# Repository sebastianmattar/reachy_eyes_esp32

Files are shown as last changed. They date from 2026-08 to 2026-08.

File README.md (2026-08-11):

# Eyes for the Reachy Mini

## Disclaimer

- This is a hobby project done with minimal professional knowledge of hardware development
- No guarantees of any kind are given
- I only tested this with my Reachy Mini Lite and MacOS
- Doing the modification can damage your robot
- Take extra care to not break the flat cables

## Motivation and journey

I wanted my Reachy Mini to have LED eyes to express different emotions.
Doing some research (googling) I figured I could combine an ESP32 with round LED displays to do it.

The cheapest way is to use very common smart watch displays (also seemingly used in some household appliances). A 1" size would have been perfect but does not seem to be widely available. I decided to check out the 1.28" sized displays.

## What this repository includes

- How you can build the hardware (PCB, holding plate)
- ESP32 program to control the eyes, plus a desktop simulator to develop the eye
  logic without hardware
- Python SDK (`reachy_eyes`) that wraps the whole eye protocol, plus command-line
  tools built on it: monitoring the robot position to drive the eyes, a keyboard
  console to poke the eyes by hand, updating the firmware over serial, and
  uploading an animated GIF for the eyes to play

## How to build the hardware

- Print the mounting plate (3d model) that holds all components
- Order the PCBA or just the PCB and solder yourself

(more infos at [`./hardware/README.md`](./hardware/README.md))

## Software

This repository provides the following:

- Simple ESP32 firmware that implements a USB serial protocol so the eyes can be controlled by the host
- Python SDK (`reachy_eyes`) that encapsulates that protocol: gaze, blinks,
  expressions, GIF upload and firmware updates
- Python tool to do firmware updates
- Python tool that monitors the robot pose and updates the eyes
- Python tool to upload an animated GIF and play it on the eyes
- Python keyboard console that triggers eye actions on real hardware — the
  simulator's key map, sent over serial

(check out [`esp32/README.md`](./esp32/README.md) and [`python/README.md`](./python/README.md))

## Changelog

| Date | Version | Description |
| --- | --- | --- |
| 2026-08-08 | 0.1 | Initial release |
| 2026-08-09 | 0.2 | - Improved mounting plate: smaller radius, eye sockets smaller<br>- Add client SDK |

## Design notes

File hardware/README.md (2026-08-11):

# Hardware

## PCB

The PCB was designed in EasyEDA Pro and ordered through its built-in JLCPCB
integration. Five boards cost me about $70 including tax and shipping, two of
them fully assembled with all parts. I picked the components so that JLCPCB's
cheaper Economic PCBA option is enough.

## Mounting plate

The 3D model is straightforward: print it in any black material you like — ABS
worked for me.

## Additional parts

- **Screws** — I just reused the ones from the Reachy Mini.
- **USB-C cable** to connect the PCB to the board -I used [these](https://www.amazon.de/dp/B0FMRND1BQ)
- **Two GC9A01 1.28" round displays** — I used
  [these](https://www.amazon.de/kreisf%C3%B6rmiger-TFT-Bildschirm-Schnittstelle-Echtzeit%C3%BCberwachung-Instrumentenanzeige/dp/B0DB5MR27T/).
  They should look like this:

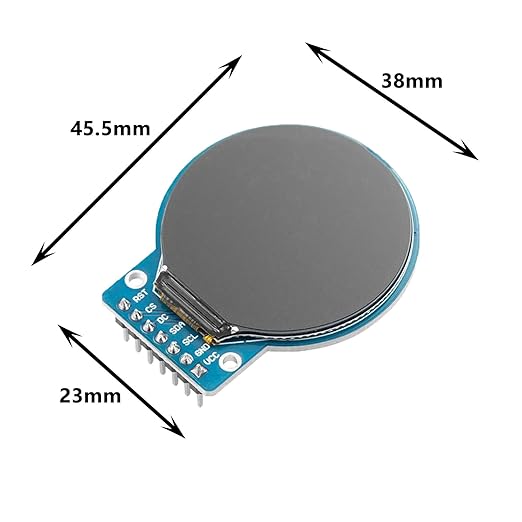
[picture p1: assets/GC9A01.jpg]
GC9A01 1.28-inch round display
  

## Getting it running

### Flash and test the PCB

Do this **before** taking the robot apart — it is much easier to debug a board
sitting on your desk than one buried in the head.

1. Plug both displays into the PCB.
2. Connect the PCB to your computer and flash the firmware (see
   [`../esp32/README.md`](../esp32/README.md)).
3. The board should boot straight into idle mode, showing both eyes wandering
   and blinking.

Only continue once you see the eyes moving.

### Assembly

Take your time here, and be careful with the flat cables — they are fragile and
easy to tear.

1. Open the front of the head, minding the camera cable.
2. Unplug the camera cable from the camera module.
3. Unscrew the camera module from the original mounting plate.
4. Unscrew the original mounting plate that holds the stock eyes.
5. Screw the camera module onto the new mounting plate.
6. Push the displays into the new mounting plate.
7. Reconnect the camera cable.
8. Plug the PCB onto the display headers and screw it to the mounting plate.
9. Connect the USB cable to the head and to the PCB.
10. Gently push the modified faceplate back onto the head, watching the
    microphone cable and taking care not to damage the camera cable. If anything
    resists, stop and find out why before pushing further.
11. Screw everything back together.

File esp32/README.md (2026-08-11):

# ESP32 firmware

Firmware that drives the two GC9A01 eye displays and exposes a line-based USB
serial protocol so the host can control them. Without commands the eyes wander
and blink on their own.

## What is in here

| Path | Contents |
| --- | --- |
| [`src/`](src/) | Implementation (`main.cpp`, eye behaviour/motion/renderer, gif player) |
| [`include/`](include/) | Headers — `config.h` (pins, geometry, firmware version), `lgfx_config.h` (display setup), `serial_protocol.h` (full command list) |
| [`sim/`](sim/) | Stubs that let the same sources build against SDL2 on the desktop |
| [`platformio.ini`](platformio.ini) | Two environments: `upesy_wroom` (hardware) and `native_sim` (desktop) |
| [`partitions.csv`](partitions.csv) | Dual OTA app slots + a LittleFS data partition for the stored gif |

## Prerequisites

- [PlatformIO](https://platformio.org/) — either the VS Code extension or the
  CLI (`pip install platformio`, or `brew install platformio` on macOS). The
  build commands below assume `pio` is on your `PATH`; the VS Code extension
  installs it to `~/.platformio/penv/bin/pio`.
- A USB serial driver for the PCB's USB-UART chip if your OS does not ship one
  (CH340 and CP210x are the usual suspects). If no port shows up in `pio device
  list` once the board is plugged in, install the vendor driver for your chip.
- Nothing else — PlatformIO downloads the ESP32 toolchain, the Arduino
  framework, and the `LovyanGFX` / `AnimatedGIF` libraries on the first build.

Before building, check [`include/config.h`](include/config.h) against your
board. The pin map there is for the PCB in [`../hardware/`](../hardware/); a
breadboard build almost certainly needs different GPIOs (see
[`../hardware/breadboard.md`](../hardware/breadboard.md)).

## Initial flash of the PCB

This is the one flash that has to happen over USB, because it also writes the
bootloader and the partition table — serial OTA later replaces only the app.

Do it **before mounting the eyes in the robot** if you can: the auto-reset that
drops the ESP32 into its bootloader is unreliable through the robot's wiring.

1. Connect the PCB to your computer with a USB-C data cable (a charge-only
   cable will not enumerate a serial port).

2. Find the port:

   ```bash
   pio device list
   # macOS: /dev/cu.usbserial-* or /dev/cu.usbmodem*
   # Linux: /dev/ttyUSB0 or /dev/ttyACM0
   ```

3. Build and flash:

   ```bash
   cd esp32
   pio run -e upesy_wroom -t upload --upload-port /dev/cu.usbserialXXXX
   ```

   Omit `--upload-port` and PlatformIO will try to autodetect it.

   If the upload stalls at `Connecting........_____`, the board did not enter
   the bootloader by itself. Hold **BOOT**, tap **EN/RST**, release **BOOT**,
   and start the upload again. If it connects but fails partway through, drop
   `upload_speed` in [`platformio.ini`](platformio.ini) — 460800 is faster,
   115200 is the safe value.

4. Verify. The displays should light up and the eyes should start wandering
   and blinking within a second or two. On the serial monitor:

   ```bash
   pio device monitor -e upesy_wroom   # 115200 baud
   ```

   You should see `Robot Eyes – starting`. Type `VERSION` and press enter — the
   board replies `VERSION 1.0.0` (whatever `FIRMWARE_VERSION` in
   [`include/config.h`](include/config.h) says). `BLINK 2` makes both eyes
   blink and answers `OK`. Most commands answer `OK` or `ERR <reason>`; the
   exceptions (`LOOK`, `VERSION`, `GIFINFO`, `GIFUPLOAD`, `FWUPDATE`) are listed
   in [`include/serial_protocol.h`](include/serial_protocol.h).

The LittleFS partition needs no flashing — it holds a single optional gif that
is uploaded at runtime with the `GIFUPLOAD` command.

### Nothing on the displays?

- Both panels dark: check the backlight pin (`TFT_BL`) and the 3V3/GND lines.
- One panel dark: that eye's `CS` or `DC` line — `TFT1_CS`/`TFT2_CS` and
  `TFT1_DC`/`TFT2_DC` in `config.h`.
- Garbled or mirrored image: `TFT_1_ROT` / `TFT_2_ROT` in `config.h`.

## Later updates

After the initial flash, updates go over the existing serial link — no
bootloader reset, no `esptool`, no buttons:

```bash
# from the repo root:
python/build_and_push.sh /dev/cu.usbmodemXXXX
```

Bump `FIRMWARE_VERSION` in [`include/config.h`](include/config.h) for each
release you want auto-deployed; the host tool only pushes when the bundled
version is newer. See [`../python/README.md`](../python/README.md) for the full
OTA workflow and the head-follow bridge.

## Desktop simulator

The eye logic (including gif playback) builds natively against SDL2, which is a
much faster loop than reflashing:

```bash
brew install sdl2          # macOS; apt install libsdl2-dev on Debian/Ubuntu
pio run -e native_sim
.pio/build/native_sim/program
```

The simulator window renders both eyes and injects serial commands from the
keyboard:

| Key | Command |
| --- | --- |
| `b` / `B` | `BLINK 1` / `BLINK 3` |
| `h` | `HEARTS` |
| `m` | `MONEY` |
| `d` | `DEAD` |
| `t` | `TRAPEZOID` |
| `s` | `SQUINT 0.3 1.5` |
| `g` / `x` | play the local gif / `STOPGIF` |
| `i` / Space | `IDLE` |
| ↑ ↓ ← → | `GAZE N` / `S` / `W` / `E` |
| `q` / Esc | quit |

`g` plays `gifs/test.gif` (relative to the working directory, so run the binary
from `esp32/`). Point `$REACHY_GIF` at another file to play that one instead:

```bash
REACHY_GIF=/path/to/other.gif .pio/build/native_sim/program
```

The same key map works against a connected board — see
[`../python/eye_console.py`](../python/eye_console.py), which sends the identical
commands over serial from a terminal:

```bash
python python/eye_console.py     # from the repo root
```

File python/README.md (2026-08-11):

### ESP32 to control the eye displays

I hacked together a software to drive the two displays with an eye logic. There is a simple protocol that works via USB (serial interface) and allows to control the eyes.

By default (if not control commands arrive) the eyes wander around and blink.

There is a simple simulation included ("native_sim") that allows you to simulate the eye behaviour on your local machine using SDL2.

### The Python SDK (`reachy_eyes`)

Everything the firmware's serial protocol offers is wrapped in one client, so you
never have to format protocol lines yourself. The command-line tools in this
directory are thin wrappers around it.

```python
from reachy_eyes import EyesClient, Direction, Eyes

with EyesClient() as eyes:          # no port given → auto-detected
    eyes.blink(2)
    eyes.gaze(Direction.NE)         # or just "NE"
    eyes.look(0.4, -0.2)            # continuous gaze target, x/y in [-1, 1]
    eyes.squint()
    eyes.hearts(Eyes.LEFT)
    eyes.set_blink_interval(2.0, 5.0)
    eyes.idle()                     # back to autonomous wandering + blinking

    eyes.upload_gif("heart.gif", play=True)
    print(eyes.gif_info())          # e.g. "18422 bytes, crc32=1B4C9A02"
    eyes.stop_gif()

    print(eyes.version())           # firmware version, or None if it can't answer
    eyes.update_firmware()          # serial OTA, only if the local build is newer
```

What the SDK handles for you:

| Concern | How |
| --- | --- |
| Finding the board | `EyesClient()` with no port scans for it; `find_port()` if you want the name |
| Replies | every command checks the `OK`/`ERR` ack and raises on failure |
| Errors | `EyesError` subclasses: `CommandError`, `EyesTimeoutError`, `CrcMismatchError`, `PortNotFoundError`, … |
| Binary transfers | `GIFUPLOAD`/`FWUPDATE` framing, chunking and CRC-32 verification |
| Firmware versions | reads `FIRMWARE_VERSION` from `config.h`, compares with the device |
| Threads | one lock serializes whole request/response exchanges, so a background streamer and foreground commands can share the link |

Modules: [`client.py`](reachy_eyes/client.py) (the API),
[`transport.py`](reachy_eyes/transport.py) (port discovery, line framing),
[`models.py`](reachy_eyes/models.py) (`Eyes`, `Direction`, results),
[`firmware.py`](reachy_eyes/firmware.py) (OTA versioning),
[`bridge.py`](reachy_eyes/bridge.py) (head-follow),
[`errors.py`](reachy_eyes/errors.py).

Importing `reachy_eyes` needs **pyserial only**; the head-follow bridge is imported
lazily because it is the one part that needs the `reachy_mini` SDK.

Running the scripts in this directory already puts the SDK on the path. To use it
from elsewhere, install it (editable):

```bash
uv pip install -e python/                    # SDK + pyserial
uv pip install -e "python/[bridge]"          # ...plus reachy-mini for EyeBridge
```

Tests run against an in-memory fake of the firmware — no hardware needed
(the bridge tests skip themselves if `reachy_mini` is missing):

```bash
python -m unittest discover -s python/tests
```

### Finding the eyes' serial port (especially inside the robot)

Every tool here takes `--port`, and every tool can also find the board itself —
`EyesClient()` with no port auto-detects. Detection is a **`VERSION` handshake**,
not a VID/PID guess, and that distinction matters once the ESP32 lives inside the
robot: a Reachy Mini Lite's internal USB hub already carries the camera, the audio
board, and the **motor controller — which is a WCH CH343 (`1a86:55d3`), the same
chip family used on ESP32 dev boards**. Guessing by USB IDs can hand you the
robot's motors; only the handshake tells the two apart. (Detection writes a single
`VERSION` line to each candidate. That is inert for the servo bus, which ignores
anything without its binary frame header.)

To see what is on the bus and which port is the eyes:

```bash
python python/eye_console.py --list-ports
```

```
  /dev/cu.usbmodem5B420746081
      USB Single Serial, 1a86:55d3, sn=5B42074608
      → not the eyes (no VERSION reply)      # this is the robot's motor controller
  /dev/cu.usbserial-0001
      USB Serial, 1a86:7523, sn=None
      → EYES — firmware 1.0.0
```

Once identified, pin it for every tool at once instead of passing `--port`:

```bash
export REACHY_EYES_PORT=/dev/cu.usbserial-0001
```

On Linux (e.g. a wireless Mini's Raspberry Pi, where the eyes enumerate on the Pi
rather than on your laptop — run these tools over ssh there) `/dev/ttyACM*`
numbering is not stable across reboots. Pin it by the board's USB serial number:

```
# /etc/udev/rules.d/99-reachy-eyes.rules
SUBSYSTEM=="tty", ATTRS{idVendor}=="1a86", ATTRS{idProduct}=="55d3", \
  ATTRS{serial}=="YOUR_BOARD_SN", SYMLINK+="reachy-eyes"
```

...then `export REACHY_EYES_PORT=/dev/reachy-eyes`.

**Nothing shows up at all?** The board is not enumerating, so no software can
reach it. In order of likelihood: a charge-only USB-C cable (very common — no data
pair); an internal connector that only carries power; a C-to-C link between two
device-role ports (neither side pulls CC up, so no data connection is negotiated);
or the board not being powered. Bisect by plugging the ESP32 into your computer
directly **with the same cable** — if it appears there, the cable and board are
fine and the robot's internal port is the problem.

### Keyboard console (the simulator, on real hardware)

[`eye_console.py`](eye_console.py) is the hardware counterpart of the desktop
simulator: single keypresses drive the connected eyes through the SDK, and each
one echoes the protocol line that went over the wire plus whatever the device
replied. Handy for bring-up, for checking a display's wiring, and for seeing what
a command actually looks like on the eyes.

```bash
python python/eye_console.py                       # port auto-detected
python python/eye_console.py --port /dev/cu.usbmodemXXXX --gif heart.gif
```

It opens with a `VERSION` handshake, so you know the link speaks the protocol
before you start pressing keys:

```
Eyes console — /dev/cu.usbmodem1101 @ 115200 baud
  → VERSION
  ✓ firmware 1.2.0 — protocol OK
```

If nothing answers it says so and still drops you at the key map — handy for
poking at firmware too old to implement `VERSION`.

| Key | Action |
| --- | --- |
| `b` / `B` | blink once / three times |
| `h` `m` `d` | hearts / money / dead eyes |
| `t` | trapezoid style |
| `s` | squint |
| `i` / Space | idle (autonomous wander + blink) |
| ↑ ↓ ← → | dart the gaze N / S / W / E |
| shift + ↑↓←→ | nudge the streamed `LOOK` target; `c` recentres it |
| `1` / `2` / `3` | aim the following commands at both / left / right eye |
| `k` | toggle a livelier auto-blink interval |
| `u` / `g` / `x` | upload the `--gif` file / play the stored gif / stop it |
| `n` / `v` | what gif is stored? / firmware version |
| `:` | type a raw protocol line |
| `?` | show the key map |
| `q` / Esc | quit (eyes go back to autonomous behavior) |

The first ten rows are the simulator's own bindings
([`esp32/src/sim/main_sim.cpp`](../esp32/src/sim/main_sim.cpp)); the rest are
things that only exist on hardware. Needs a POSIX terminal (macOS/Linux) and
`pyserial`. Firmware updates are deliberately not bound — that is
[`ota_update.py`](ota_update.py)'s job.

### Motion-linked eyes (head-follow bridge)

[`eye_bridge.py`](eye_bridge.py) mirrors the robot's head
motion onto the eyes in real time: it reads Reachy Mini's head pose from the SDK
and streams a continuous gaze target to the ESP32 over USB serial, so the eyes
follow every motion — and it blinks on large gaze shifts and squints on antenna
deflection.

**Requirements:** the `reachy_mini` SDK (which pulls in `numpy`, `scipy`, and
`pyserial`). Use **Python 3.12** — the SDK pins deps (onnxruntime, a bundled
GStreamer) that have no 3.14 wheels yet.

Set up the environment from the repo root (needs [uv](https://docs.astral.sh/uv/)):

```bash
uv venv --python 3.12                     # (re)create the .venv on Python 3.12
source .venv/bin/activate
uv pip install "reachy-mini"   # SDK + numpy, scipy, pyserial (large download)
```

Run the bridge (the port is auto-detected; pass `--port` to be explicit):

```bash
python python/eye_bridge.py

ls /dev/cu.*   # macOS: pick the /dev/cu.usbmodem* that is the ESP32
               #        (replug it and rerun to see which entry appears)
               # Linux: the port is /dev/ttyACM0 or /dev/ttyUSB0
python python/eye_bridge.py --port /dev/cu.usbmodemXXXX
```

Or embed it in your own app — the bridge shares one `ReachyMini` instance with your
code, and `bridge.eyes` is the full SDK client:

```python
from reachy_mini import ReachyMini
from reachy_eyes import EyeBridge

with ReachyMini() as mini, EyeBridge(mini) as bridge:
    ...                          # your robot behavior; the eyes follow along
    bridge.override()            # pause head-follow
    bridge.eyes.hearts()         # scripted eyes
    bridge.release()             # hand control back to head-follow
```

> If an existing `.venv` fails to run, it likely points at a Homebrew Python that
> has since been upgraded — recreate it with the `uv venv` command above.

### Playing an animated GIF on the eyes

The firmware keeps one GIF in its LittleFS partition (up to 1 MB) and can loop it
on both eyes instead of the normal eye rendering.
[`upload_gif.py`](upload_gif.py) drives that over the same serial link:

```bash
# Upload a gif (verifies the device's CRC-32 against a locally computed one):
python python/upload_gif.py heart.gif

# Upload and start playing it immediately (--port is optional everywhere):
python python/upload_gif.py --port /dev/cu.usbmodemXXXX heart.gif --play

# What is currently stored? (byte length + crc32, or NONE)
python python/upload_gif.py --info

# Stop playback and go back to the autonomous eye behavior:
python python/upload_gif.py --stop
```

Uploading overwrites the single stored slot. Requires `pyserial` only — no
`reachy_mini` SDK needed.

### Updating the ESP32 firmware (serial OTA)

Once the eyes are mounted in the robot, USB re-flashing with PlatformIO is
painful — the auto-reset that puts the ESP32 into its bootloader often fails
through the robot's wiring. So the firmware can update **itself over the existing
USB serial link**: the running firmware writes the new image into the spare OTA
partition via the ESP32 `Update` API and reboots into it. No bootloader reset, no
`esptool`, no BOOT/EN buttons.

Tools in this directory (paths below are relative to the repo root):

```bash
# Compare the running firmware vs the bundled version, no changes:
python python/ota_update.py --check-only

# Push the built firmware if it is newer than what the board runs:
python python/ota_update.py

# Build, then push in one step:
python/build_and_push.sh /dev/cu.usbmodemXXXX
```

`eye_bridge.py` can also update on startup before it begins streaming:

```bash
python python/eye_bridge.py --update-firmware
```

From Python it is one call — `EyesClient.update_firmware()`, which returns an
`UpdateStatus` (`updated`, `up-to-date`, `no-device`, `pushed-unverified`).

How the version check works: the firmware reports its version (`VERSION`
command), which the host compares against `FIRMWARE_VERSION` in
[esp32/include/config.h](../esp32/include/config.h) — the single source of truth.
Bump that string on each release you intend to auto-deploy. The update is pushed
only when the bundled version is newer (use `--force` to override).

> **First time only:** the board must already run OTA-capable firmware with the
> dual-slot [partitions.csv](../esp32/partitions.csv). Flash _that_ build once over
> USB with PlatformIO (it also lays down the new partition table); every update
> after that can go over serial. Serial OTA replaces the app only, not the
> bootloader or partition table.

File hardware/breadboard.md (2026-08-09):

## Hardware (breadboard prototype only)

### Required

- ESP32 ( I have the NodeMCU Wroom ESP32 )
- 2xGC9A01 1.28" round displays
- Breadboard
- Some wires

### Wiring

May vary according to your specific ESP32 model. The "Display pin" column is the
pin number on the GC9A01 module's own connector (see the pinout below).

| GC9A01 (left) | GC9A01 (right) | Pin ESP32 | Display pin | GPIO |
| --- | --- | --- | --- | --- |
| GND | GND | GND | 1 | |
| VCC | VCC | 3V3 | 2 | |
| SCL | SCL | D18 | 3 | GPIO18 / SCK |
| SDA | SDA | D23 | 4 | MOSI / GPIO23 / VSPI-D  |
| RST | RST | D4 | 5 | GPIO4 / HSPI-HD |
| DC | DC | D2 | 6 | GPIO2 |
| CS | | D14 | 7 | GPIO14 |
| | CS | D15 | 7 | GPIO15 / HSPI-CS0 |

Both displays share every line except `CS` — that is what lets one SPI bus drive
two panels.

#### Connectors GC9A01

1. GND (Power Supply Ground)
2. VCC (Power Supply Positive)
3. SCL (Clock Line)
4. SDA (Data Line)
5. RES (Reset Line)
6. DC (Data/Command)
7. CS (Chip Select)

### Get the software running on your ESP32

Prerequisites:

- Visual Studio Code
- PlatformIO

Make sure to update `include/config.h` to your configuration.

### From breadboard to something better

It took about 2 hours of trying my luck with a soldering iron to get to the conclusion I could not do it myself - lacking the skills and the equipment. 12 hours after learning the meaning of the word "PCB" I came up with a very simple PCB design that I ordered at https://jlcpcb.com/.

Goal is to use flat cables to connect the displays to the PCB.

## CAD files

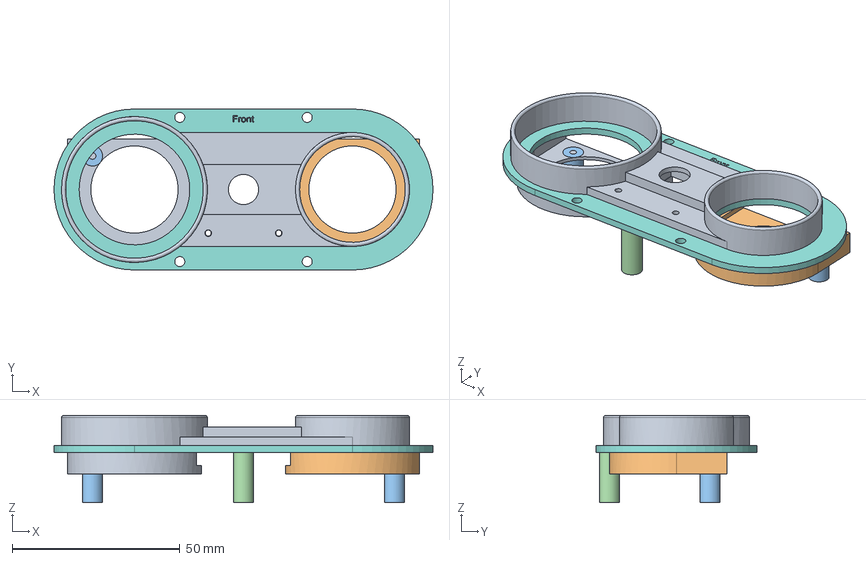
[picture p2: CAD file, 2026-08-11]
hardware/3d Print/Mounting Plate 0.2.step
113.0 x 48.0 x 26.0 mm

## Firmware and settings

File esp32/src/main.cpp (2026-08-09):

#include <Arduino.h>
#include "defs.h"
#ifndef SIMULATOR
#include "lgfx_config.h"
#include <LittleFS.h>
#endif
#include "gif_player.h" // portable now — runs in the simulator too
#include "eye_behavior.h"
#include "eye_motion.h"
#include "eye_renderer.h"
#include "fps_counter.h"
#include "serial_protocol.h"

// ─── Globals ─────────────────────────────────────────────────────────────────

// Two display instances — each owns its CS pin; LovyanGFX manages CS internally.
// Only display0 pulses the shared RST line; display1 uses rst=-1 to avoid
// resetting display0 after it has already been initialised.
static LGFX_Eye display0(TFT1_CS, TFT1_DC, TFT_RST); // left eye  — pulses RST on init
static LGFX_Eye display1(TFT2_CS, TFT2_DC, -1);      // right eye — no RST pulse
// Two sprite buffers so we can render eye 1 while eye 0's DMA transfer runs.
// Each 200×200×16-bit = 80 KB; 160 KB total (fits ESP32 WROOM DRAM without PSRAM).
static LGFX_Sprite sprite0(&display0);
static LGFX_Sprite sprite1(&display1);

static EyesControllerLowLevel lowController;
static EyesControllerHighLevel highController;
static uint32_t lastMicros = 0;
static FpsCounter fpsCounter;
static SerialProtocol serialProtocol(highController);
static GifPlayer gifPlayer;

// ─── Setup ───────────────────────────────────────────────────────────────────

void setup()
{
    Serial.begin(115200);
    Serial.println("Robot Eyes – starting");

    // Backlight on
    pinMode(TFT_BL, OUTPUT);
    analogWrite(TFT_BL, BACKLIGHT_MAX);

    // Initialise displays — both init() calls first so that display0's RST
    // pulse (inside display0.init()) resets both panels while both are still
    // uninitialised.  display1 has rst=-1, so it will not pulse RST and
    // will not accidentally reset display0 a second time.
    display0.init();
    display1.init();
    display0.setRotation(TFT_1_ROT);
    display1.setRotation(TFT_2_ROT);
    display0.fillScreen(TFT_BLACK);
    display1.fillScreen(TFT_BLACK);

    // Enable GC9A01 internal brightness control and set to maximum.
    // 0x53 WRCTRLD: bit3=BCTRL (enable brightness), bit2=DD (display dimming)
    // 0x51 WRDISBV: display brightness value (0x00–0xFF)
    // seems to get a minor brightness boost
    for (auto *d : {&display0, &display1})
    {
        d->startWrite();
        d->writeCommand(0x53);
        d->writeData(0x2C); // WRCTRLD: enable BCTRL + DD
        d->writeCommand(0x51);
        d->writeData(0xFF); // WRDISBV: max brightness
        d->endWrite();
    }

    // Allocate two frame-buffer sprites (16-bit, 200×200 = 80 KB each, 160 KB total)
    sprite0.setColorDepth(16);
    sprite1.setColorDepth(16);
    Serial.printf("Free heap before sprite alloc: %u bytes\n", ESP.getFreeHeap());
    if (!sprite0.createSprite(SCREEN_W, SCREEN_H) ||
        !sprite1.createSprite(SCREEN_W, SCREEN_H))
    {
        Serial.println("ERROR: sprite RAM allocation failed.");
        while (true)
        {
        }
    }
    Serial.printf("Free heap after sprite alloc:  %u bytes\n", ESP.getFreeHeap());

#ifndef SIMULATOR
    // Mount flash storage for the uploaded gif (format on first boot).
    if (!LittleFS.begin(true))
        Serial.println("WARN: LittleFS mount failed — gif upload/playback disabled.");
#endif
    // The gif decoder writes straight into the two sprite framebuffers.
    // (In the simulator the gif is loaded from a local file instead of LittleFS.)
    gifPlayer.begin(&sprite0, &sprite1);
    serialProtocol.attachGifPlayer(&gifPlayer);

    // Initialise eyes controller stack
    lowController.init();
    highController.init(&lowController);

    lastMicros = micros();
    Serial.println("Ready.");
}

// ─── Loop ────────────────────────────────────────────────────────────────────

void loop()
{
    // Delta time in seconds (clamped to 100 ms max to avoid large jumps)
    uint32_t now = micros();
    float dt = (float)(now - lastMicros) * 1e-6f;
    lastMicros = now;
    if (dt > 0.1f)
        dt = 0.1f;

    serialProtocol.poll();
    highController.update(dt);

    // Advance animation through low-level controller
    lowController.update(dt);

    // ── Render + push with DMA overlap ─────────────────────────────────────
    // Render eye 0 into sprite0, then start its DMA transfer (non-blocking).
    // While the SPI DMA runs, render eye 1 into sprite1 on the CPU.
    // Wait for DMA completion, then push eye 1 synchronously.
    // This hides ~7 ms of SPI idle time behind useful CPU work.

    if (lowController.getEyeRendererKind(0) == EYE_RENDERER_GIF)
    {
        // GIF mode: one decode composites the same frame into both sprites.
        // Only advances the decoder when the current frame's delay has elapsed;
        // otherwise the sprites keep holding the current frame.
        uint32_t t0 = micros();
        gifPlayer.update(dt);
        uint32_t t1 = micros();

        // Push both eyes via the existing DMA-overlap path.
        sprite0.pushSprite(SPRITE_PUSH_X, SPRITE_PUSH_Y);
        display0.waitDisplay();
        uint32_t t2 = micros();
        sprite1.pushSprite(SPRITE_PUSH_X, SPRITE_PUSH_Y);
        uint32_t t4 = micros();

        fpsCounter.record(t1 - t0, t2 - t1, 0, t4 - t2);
        return;
    }

    uint32_t t0 = micros();
    getEyeRenderer(lowController.getEyeRendererKind(0)).render(sprite0, lowController.getAnimationState(0));
    uint32_t t1 = micros();

    // Start DMA push for eye 0 (returns before transfer completes)
    sprite0.pushSprite(SPRITE_PUSH_X, SPRITE_PUSH_Y);

    // Render eye 1 while eye 0 transfers over SPI
    getEyeRenderer(lowController.getEyeRendererKind(1)).render(sprite1, lowController.getAnimationState(1));
    uint32_t t3 = micros();

    // Wait for eye 0 DMA to finish
    display0.waitDisplay();
    uint32_t t2 = micros();

    // Push eye 1 synchronously
    sprite1.pushSprite(SPRITE_PUSH_X, SPRITE_PUSH_Y);
    uint32_t t4 = micros();

    fpsCounter.record(t1 - t0, t2 - t1, t3 - t2, t4 - t3);
}

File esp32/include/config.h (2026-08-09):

#pragma once

// ── Hardware ─────────────────────────────────────────────────────────────────
#define NUM_EYES 2
#define TFT1_CS 5  // Chip-select for display 0 (left eye)
#define TFT2_CS 17 // Chip-select for display 1 (right eye)
#define TFT1_DC 16
#define TFT2_DC 25
#define TFT_SDA 23
#define TFT_CLK 18
#define TFT_RST 26        // Shared reset pin (both displays)
#define TFT_BL 22         // Backlight PWM pin
#define TFT_1_ROT 2       // Display 0 rotation (0–3)
#define TFT_2_ROT 2       // Display 1 rotation (0–3)
#define BACKLIGHT_MAX 255 // PWM backlight level (0–255)

// ── Display ──────────────────────────────────────────────────────────────────
// GC9A01 native res is 240×240.
// Sprite is 200×200 (80 KB) – fits ESP32 heap reliably without PSRAM.
// It is pushed centered at (SPRITE_PUSH_X, SPRITE_PUSH_Y) on the 240×240 display;
// the 20 px corners are clipped by the circular GC9A01 bezel anyway.
#define SCREEN_W 200
#define SCREEN_H 200
#define SPRITE_PUSH_X 20 // pixel offset when pushing sprite onto 240×240 display
#define SPRITE_PUSH_Y 20

#define CX (SCREEN_W / 2)
#define CY (SCREEN_H / 2)

// Physical display circle: radius 120 px on the 240×240 panel.
// In sprite coordinates the circle is centred at (CX, CY) with the same radius
// because SPRITE_PUSH_X == SPRITE_PUSH_Y == 120 - SCREEN_W/2.
#define DISPLAY_RADIUS 120

// ── Dot-grid eye geometry ─────────────────────────────────────────────────────
#define GRID_SPACING 12 // Pixels between dot centres
#define DOT_RADIUS 5    // Radius of each lit dot (px)
#define GRID_COLS (SCREEN_W / GRID_SPACING)
#define GRID_ROWS (SCREEN_H / GRID_SPACING)

// Pupil bounding half-extents at scale=1.0, aspect=1.0
#define PUPIL_BASE_W (SCREEN_W * 0.60f) // ~120 px on 200px sprite
#define PUPIL_BASE_H (SCREEN_H * 0.45f) // ~90 px

// ── Blink timing (seconds) ───────────────────────────────────────────────────
#define BLINK_CLOSE_S 0.045f
#define BLINK_HOLD_S 0.005f
#define BLINK_OPEN_S 0.065f

// ── Idle wander ──────────────────────────────────────────────────────────────
#define WANDER_EXTENT_X 0.70f // Max gaze travel on X (−1..+1 = full iris travel)
#define WANDER_EXTENT_Y 0.55f
#define WANDER_DWELL_MIN 0.5f // Seconds at a position before next move
#define WANDER_DWELL_MAX 3.0f

// ── Autoblink fallback interval (used by shared countdown in main.cpp) ────────
#define BLINK_INTERVAL_DEFAULT_MIN 3.0f // Seconds
#define BLINK_INTERVAL_DEFAULT_MAX 6.0f

// ── Dart spring (used by both gaze demo and idle wander) ─────────────────────
// Underdamped dart spring used for directed gaze and idle wander.
// Critical damping = 2*sqrt(k); e.g. for k=700 that is ≈53.
#define DART_SPRING_K 700.0f      // Stiffness during dart
#define DART_SPRING_DAMPING 12.0f // Underdamped — gives the snap

// ── Hearts animation ─────────────────────────────────────────────────────────
#define HEARTS_DURATION_S 2.5f // Seconds before returning to default eye mode

// ── Firmware version ──────────────────────────────────────────────────────────
// Reported by the serial `VERSION` command; the host OTA tool compares it against
// the version baked into a firmware.bin to decide whether to push an update.
// Bump this on every release you intend to auto-deploy.
#define FIRMWARE_VERSION "1.0.0"

// ── Animated GIF playback ─────────────────────────────────────────────────────
#define GIF_PATH "/eye.gif"               // Single-slot stored GIF (LittleFS)
#define GIF_MAX_BYTES (1024u * 1024u)     // Upload size cap (spiffs partition ~1.3 MB)
#define GIF_UPLOAD_TIMEOUT_MS 3000        // Abort upload after this idle gap (ms)

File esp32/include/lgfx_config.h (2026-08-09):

#pragma once
// ─── LovyanGFX hardware configuration for dual GC9A01 displays ───────────────
// Create two LGFX_Eye instances in main.cpp, one per CS pin:
//   static LGFX_Eye display0(TFT1_CS);
//   static LGFX_Eye display1(TFT2_CS);
// Both share VSPI_HOST at 80 MHz; each manages its own CS signal.
// bus_shared = true tells LovyanGFX to arbitrate the bus between instances.

#include <LovyanGFX.hpp>

class LGFX_Eye : public lgfx::LGFX_Device
{
    lgfx::Panel_GC9A01 _panel;
    lgfx::Bus_SPI _bus;

public:
    // rst_pin: pass TFT_RST for the first display, -1 for the second so the
    // shared hardware RST line is only pulsed once (during display0.init()).
    explicit LGFX_Eye(int cs_pin, int dc_pin, int rst_pin = -1)
    {
        {
            auto cfg = _bus.config();
            cfg.spi_host = VSPI_HOST; // SPI3 on ESP32 WROOM (MOSI=23, SCLK=18)
            cfg.spi_mode = 0;
            cfg.freq_write = 80000000;
            cfg.freq_read = 16000000;
            cfg.pin_sclk = TFT_CLK;
            cfg.pin_mosi = TFT_SDA;
            cfg.pin_miso = -1;
            cfg.pin_dc = dc_pin;
            cfg.use_lock = true; // required when bus is shared between instances
            _bus.config(cfg);
            _panel.setBus(&_bus);
        }
        {
            auto cfg = _panel.config();
            cfg.pin_cs = cs_pin;
            cfg.pin_rst = rst_pin;
            cfg.pin_busy = -1;
            cfg.panel_width = 240;
            cfg.panel_height = 240;
            cfg.memory_width = 240;
            cfg.memory_height = 240;
            cfg.offset_x = 0;
            cfg.offset_y = 0;
            cfg.offset_rotation = 0;
            cfg.dummy_read_pixel = 8;
            cfg.dummy_read_bits = 1;
            cfg.readable = false;
            cfg.invert = true; // GC9A01 requires color inversion
            cfg.rgb_order = false;
            cfg.dlen_16bit = false;
            cfg.bus_shared = true; // shared SPI bus with the other display
            _panel.config(cfg);
        }
        setPanel(&_panel);
    }
};
